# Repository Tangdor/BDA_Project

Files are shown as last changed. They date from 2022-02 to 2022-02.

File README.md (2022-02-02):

# Create your own BDA!

***
First, this is a university student project, BDA. It stands for Box Displayed Api's.

The purpose of our project is to develop an easy and fast device to facilitate daily tasks for students. 

Additionally, students should have the opportunity to continue to expand our device and its functions independently through their own ideas.

Among other things, this readme is here to make it easier for you to rebuild the device and the implementation that comes with it.
***

# Installation

## Hardware
What component parts are needed?:

- Raspberry PI Zero v.1.3, 1 Ghz, 512 MB Ram [1].

- The Waveshare 1.5 inch RGB OLED display [2].

- The rotary encoder is the AZ Delivery 5 * KY-040 [3].

In addition, sensors can still be attached. In our case we use 

- the gesture sensor Hailege 2pcs APDS-9960 APDS9960 RGB [4] 
- the temperature sensor AZDelivery DHT22 AM2302 [5]

<b> Raspberry Pi's Layout </b>

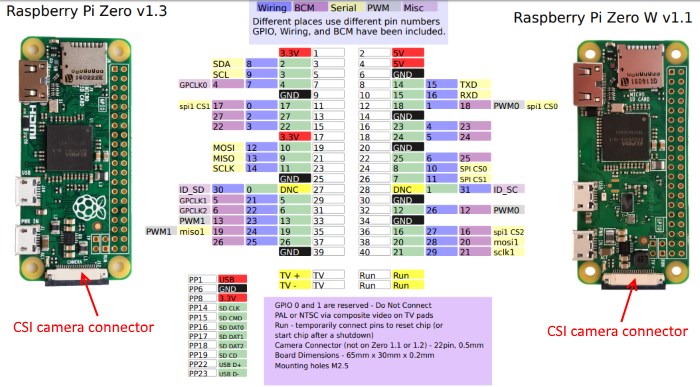
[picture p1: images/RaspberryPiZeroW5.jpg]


<b> Wiring diagram (simplified) </b>

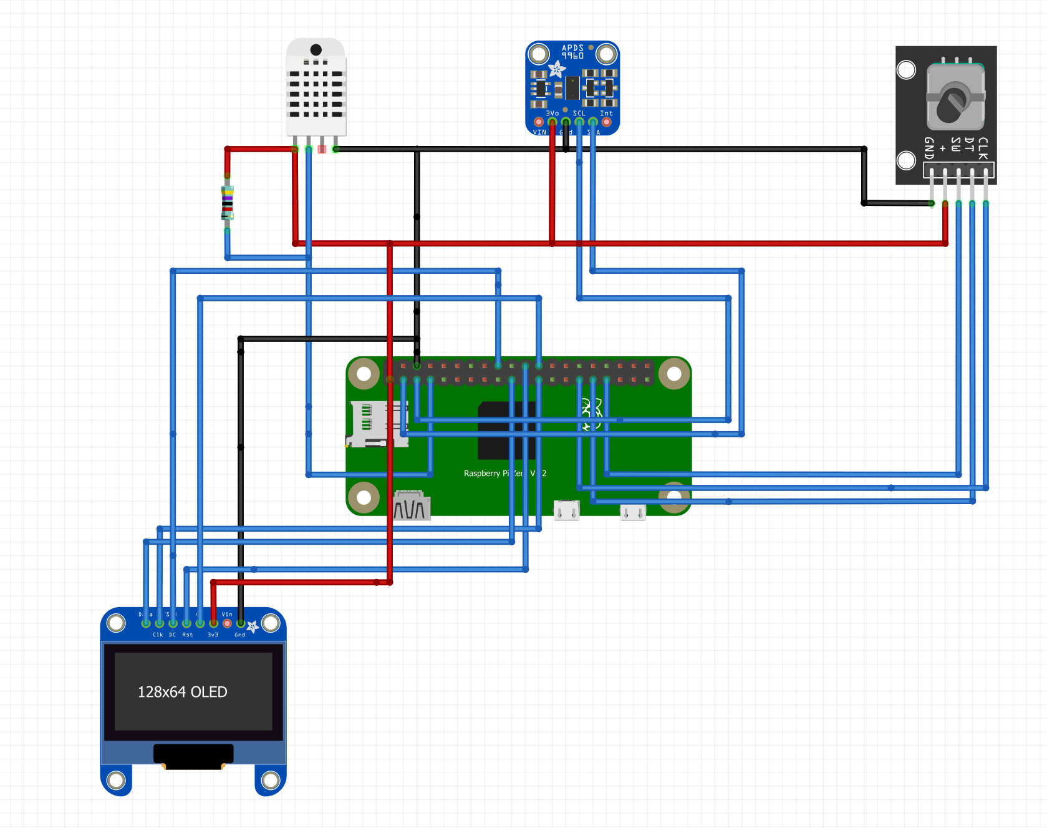
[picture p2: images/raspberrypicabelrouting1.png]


<b> Wiring diagram (detailed)  </b>

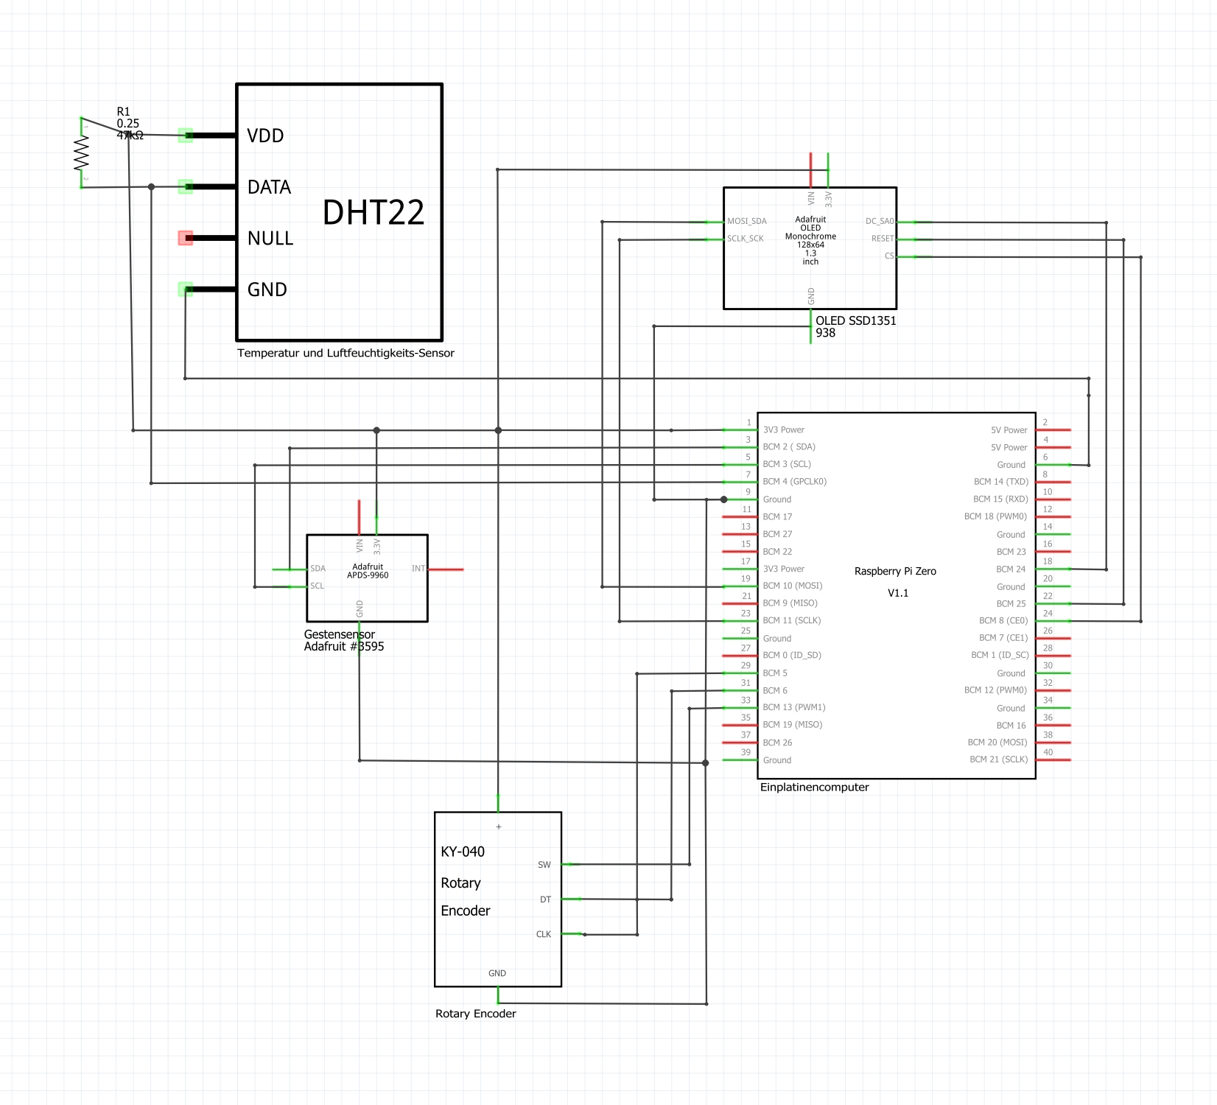
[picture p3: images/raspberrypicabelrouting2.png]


<b> The color affiliation for the cables are personalized, which means that it doesn't really matter how they are wired. 
It is only our choice of colors  </b>

<b>  Display </b>

| Raspberry Pi  | Color cable | Display  |
| --- | --- | --- |
| 3.3V 1 | red  | Vcc  |
| Ground 6 | black  | Ground  |
| MOSI bcm10  | blue  | MOSI  |
| SCLK bcm11  | yellow  | Clock  |
| SPICS0 bcm8  | orange  | CS (chip select) |
| bcm24  | green | DC (Data command)  |
| bcm25  | white  | reset  |

<b>  Rotary Encoder </b>

| Raspberry Pi  | Color cable | Rotary Encoder  |
| --- | --- | --- |
| GPIO 5 | purple  | CLK  |
| GPIO 6 | white  | DT  |
| GPIO 13  | yellow  | MOSI  |
| 3.3V  | red  | + |
| GND  | black  | GND|

<b> DHT22 </b>

| Raspberry Pi  | Color cable | DHT22  |
| --- | --- | --- |
| GND | black  | GND  |
| 3.3v | red  | VDD  |
| GPIO 4  | green  | DATA  |

<b> APDS9960 </b>

| Raspberry Pi  | Color cable | APDS9960  |
| --- | --- | --- |
| GND | black  | GND  |
| 3.3v | orange/red  | VCC  |
| SDA BCM2 PIN3  | green  | SDA  |
| SCL BCM3 PIN5  | white  | SCL  |

## Software
 - The Flask framework must be installed. [6]
### References
<b> For the individual installations I will direct you to the GitHub repositories. There you will find out more </b>

#### gesture sensore [8]

#### display  [9]

#### volume changer [10]

- pip install pycaw
- pip install comtypes

#### email  [11]

#### temperature sensor [12]

Website links: 

<b>  The website links I show you here might not be up to date at a later date. </b>

[1]: https://www.reichelt.de/de/de/raspberry-pi-zero-v-1-3-1-ghz-512-mb-ram-rasp-pi-zero-p256439.html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

[2]: https://www.amazon.de/gp/product/B07DB5YFGW/ref=ppx_yo_dt_b_asin_title_o01_s00?ie=UTF8&psc=1

[3]: https://www.amazon.de/AZDelivery-KY-040-Encoder-Compatible-Arduino/dp/B07CMVQHLT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

[4]: https://www.amazon.de/Gestensensormodul-Handgestenerkennung-Bewegungsrichtung-N%C3%A4herungssensor-Bewegungssensor/dp/B07YJDBFSD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

[5]: https://www.amazon.de/dp/B06XF4TNT9/ref=cm_sw_r_oth_api_glt_i_12DKYP86ENPG24TRVQXB?_encoding=UTF8&psc=1

[6]: https://code.visualstudio.com/docs/python/tutorial-flask

[7]: https://github.com/conradstorz/KY040

[8]: https://github.com/liske/python-apds9960

[9]: https://www.bluetin.io/displays/oled-display-raspberry-pi-ssd1331/

[10]: https://github.com/AndreMiras/pycaw

[11]: https://www.thepythoncode.com/article/reading-emails-in-python

[12]: https://github.com/adafruit/Adafruit_Python_DHT

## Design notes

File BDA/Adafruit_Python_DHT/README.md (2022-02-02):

*DEPRECATED LIBRARY* Adafruit Python DHT Sensor Library
=======================

his library has been deprecated! We are leaving this up for historical and research purposes but archiving the repository.

We are now only supporting the use of our CircuitPython libraries for use with Python.

Check out this guide for info on using DHT sensors with the CircuitPython library: https://learn.adafruit.com/dht-humidity-sensing-on-raspberry-pi-with-gdocs-logging/python-setup

---------------------------------------

Python library to read the DHT series of humidity and temperature sensors on a
Raspberry Pi or Beaglebone Black.

Designed specifically to work with the Adafruit DHT series sensors ---->
https://www.adafruit.com/products/385

Currently the library is tested with Python 2.6, 2.7, 3.3 and 3.4. It should
work with Python greater than 3.4, too.

Installing
----------

### Dependencies

For all platforms (Raspberry Pi and Beaglebone Black) make sure your system is
able to compile and download Python extensions with **pip**:

On Raspbian or Beaglebone Black's Debian/Ubuntu image you can ensure your
system is ready by running one or two of the following sets of commands:

Python 2:

````sh
sudo apt-get update
sudo apt-get install python-pip
sudo python -m pip install --upgrade pip setuptools wheel
````

Python 3:

````sh
sudo apt-get update
sudo apt-get install python3-pip
sudo python3 -m pip install --upgrade pip setuptools wheel
````

### Install with pip

Use `pip` to install from PyPI.

Python 2:

```sh
sudo pip install Adafruit_DHT
```

Python 3:

```sh
sudo pip3 install Adafruit_DHT
```

### Compile and install from the repository

First download the library source code from the [GitHub releases
page](https://github.com/adafruit/Adafruit_Python_DHT/releases), unzipping the
archive, and execute:

Python 2:

```sh
cd Adafruit_Python_DHT
sudo python setup.py install
```

Python 3:

```sh
cd Adafruit_Python_DHT
sudo python3 setup.py install
```

You may also git clone the repository if you want to test an unreleased
version:

```sh
git clone https://github.com/adafruit/Adafruit_Python_DHT.git
```

Usage
-----

See example of usage in the examples folder.

Author
------

Adafruit invests time and resources providing this open source code, please
support Adafruit and open-source hardware by purchasing products from Adafruit!

Written by Tony DiCola for Adafruit Industries.

MIT license, all text above must be included in any redistribution

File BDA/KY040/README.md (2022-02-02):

#KY040 Python Module 
##Martin O'Hanlon (martin@ohanlonweb.com)
##http://www.stuffaboutcode.com

##Description
A python module for reading the values from a KY040 rotary encoder module using a raspberry pi [http://www.stuffaboutcode.com/2015/05/raspberry-pi-and-ky040-rotary-encoder.html]([http://www.stuffaboutcode.com/2015/05/raspberry-pi-and-ky040-rotary-encoder.html])

##Version history
* 0.1 - Initial stable version
* 0.2 - Minor improvement

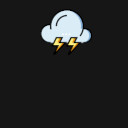
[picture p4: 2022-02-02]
BDA/weatherThunderstorm.jpg

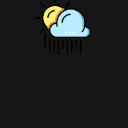
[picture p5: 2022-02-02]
BDA/weatherRain.jpg

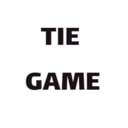
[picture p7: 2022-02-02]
BDA/tie.jpg

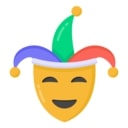
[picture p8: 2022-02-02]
BDA/jokeApp.jpg

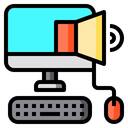
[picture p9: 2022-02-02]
BDA/computer.jpg

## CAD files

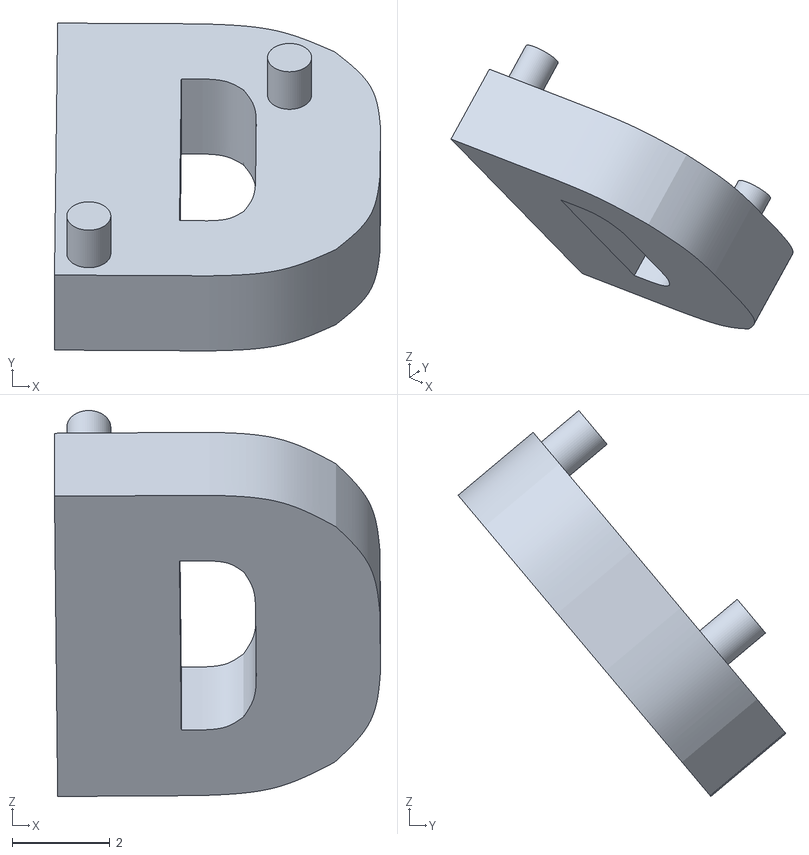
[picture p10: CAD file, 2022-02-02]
Model/Front label text D.stl
6.66 x 6.69 x 7.88

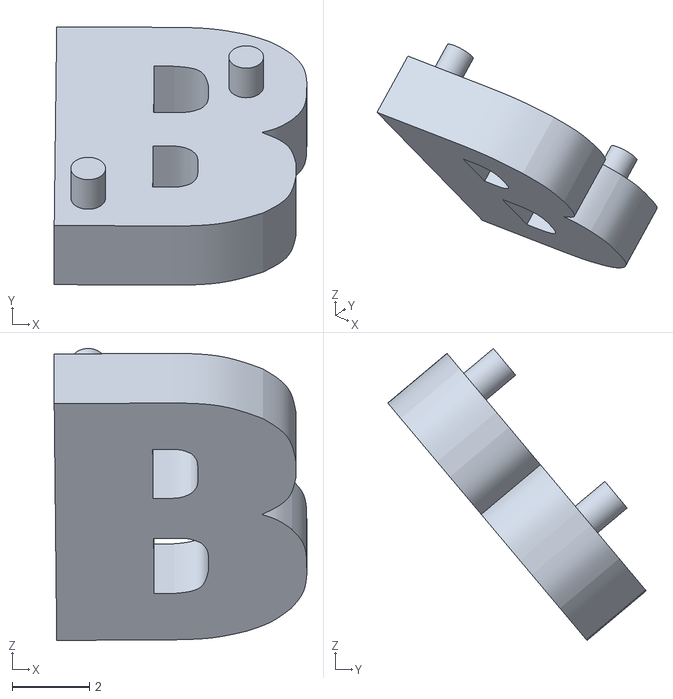
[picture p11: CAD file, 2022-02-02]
Model/Front label text B.stl
6.54 x 6.69 x 7.56

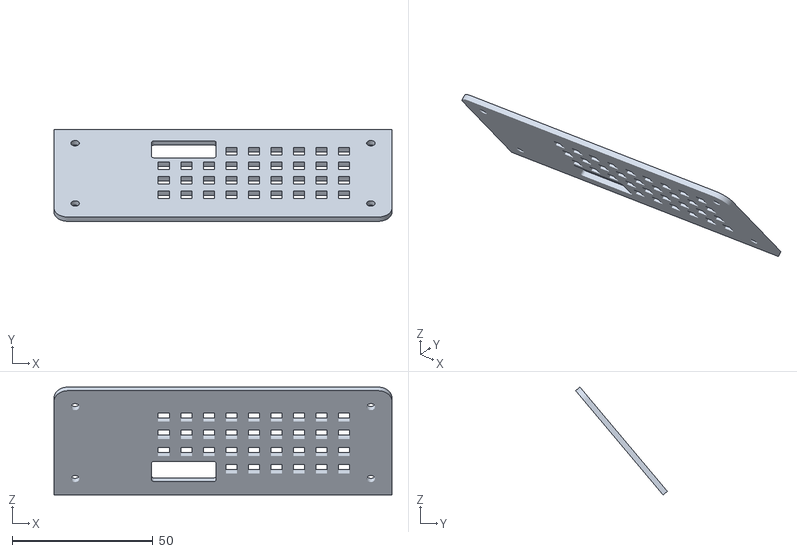
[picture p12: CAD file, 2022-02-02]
Model/Rear case doori.stl
120.0 x 32.6 x 38.3

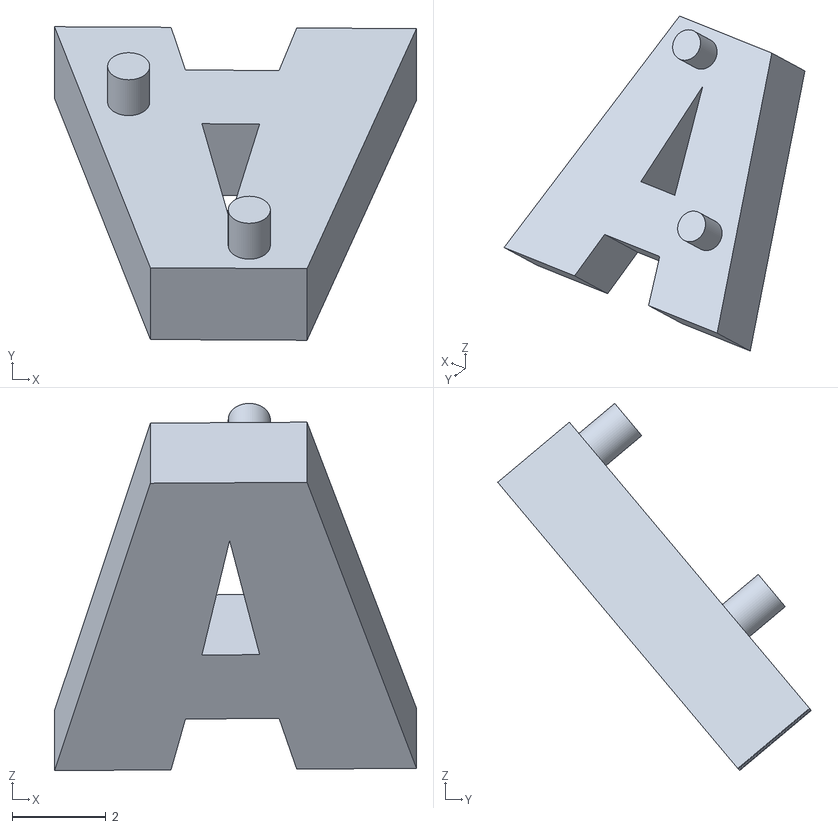
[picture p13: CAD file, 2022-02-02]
Model/Front label text A.stl
7.74 x 6.70 x 7.85

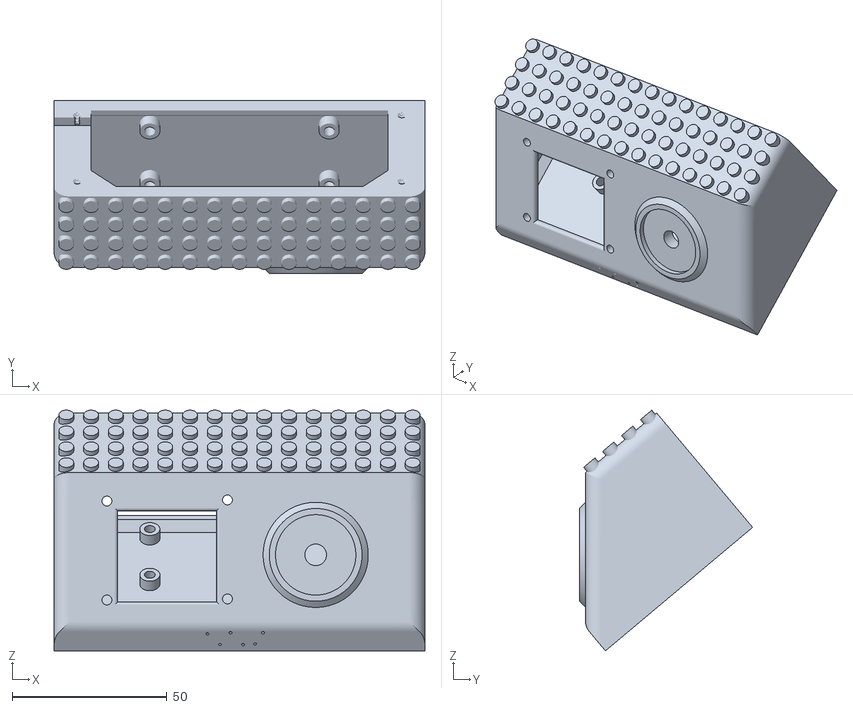
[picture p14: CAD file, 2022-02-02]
Model/BDA.stl
120.0 x 56.0 x 77.9

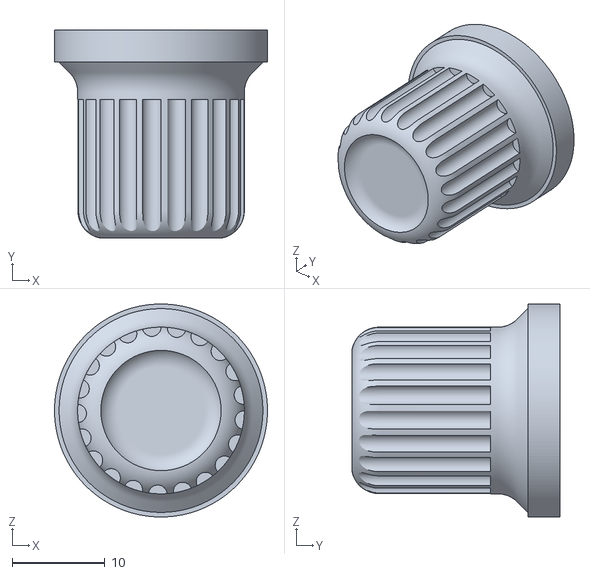
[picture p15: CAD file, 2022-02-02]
Model/Knob.stl
23.0 x 22.5 x 23.0

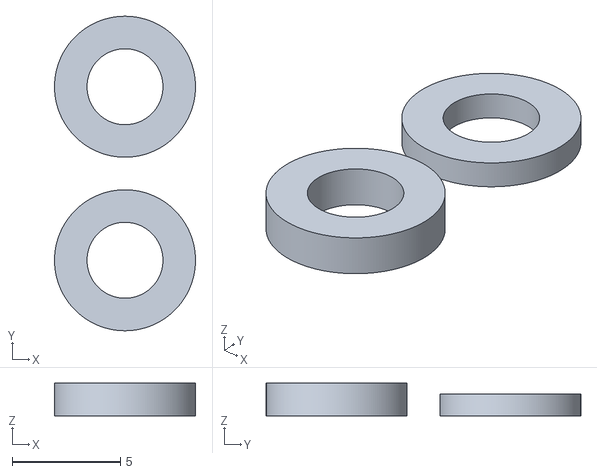
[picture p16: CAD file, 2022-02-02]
Model/Washer.stl
6.50 x 14.5 x 1.50

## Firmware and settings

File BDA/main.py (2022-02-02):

from apds9960.const import *
from apds9960 import APDS9960
import RPi.GPIO as GPIO
import smbus
from time import sleep
import math
import time
import datetime
from demo_opts import get_device
from luma.core.render import canvas
from KY040.KY040 import KY040
import os
from PIL import Image
from PIL import ImageDraw
from PIL import ImageFont
from luma.core.interface.serial import spi
from luma.oled.device import ssd1351
import sys
from TTTField import TTTField
import requests
import json
from flask import Flask,make_response
import configparser
from urllib.request import urlopen
import xmltodict 
from requests.structures import CaseInsensitiveDict
import imaplib
import email
from email.header import decode_header
import webbrowser
import Adafruit_DHT


app = Flask(__name__)

# Sensortype and GPIO for the temperaturesensor
sensor = Adafruit_DHT.DHT22
pin = '4'

# Initialization of the display
serial= spi(device=0, port=0)
device = ssd1351(serial_interface=serial, width=128, height=128, rotate=2, framebuffer=None, h_offset=0, v_offset=0, bgr=True)



# URL to the tomtom api
apiURL      = "https://api.tomtom.com/routing/1/calculateRoute/"
# apiKey
apiKey      = "insert your created TomTom API key"





# Variables for the volume app
muted = False
inVolumeApp = False
pressedCounter = 0
volumeCounter = 20



# this is used for the app menue, to keep track when a new app should be displayed and which
oldState = True 
counterPictures = 0 

# this is used for TicTacToe to keep track of what we should display
counterField = 0 
oldField = True 
xMarker = True 
movedField = True 
counterMarked = 0

# Variables used to keep track what we should display in each app
weatherCounter = 0
weatherOldState = True
trafficCounter = 0
trafficOldState = True
coronaCounter = 0
coronaOldState = True
mailCounter = 0
mailOldState = True
jokeCounter = 0
jokeOldState = True
calendarCounter = 0
calendarOldState = True
trainCounter = 0
trainOldState = True

# account credentials
username = "aliuetest99@gmail.com"
password = "#!test!#"

# Initialization of the motion sensor , every motion we use, we use inverted since our motion sensor is mounted on its head on our BDA, so left is right etc.
port = 1
bus = smbus.SMBus(port)
apds = APDS9960(bus)

# fields for our TicTacToe App
Field1 = TTTField(1,1,1,False,"")
Field2 = TTTField(41,1,2,False,"")
Field3 = TTTField(81,1,3,False,"")
Field4 = TTTField(1,41,4,False,"")
Field5 = TTTField(41,41,5,False,"")
Field6 = TTTField(81,41,6,False,"")
Field7 = TTTField(1,81,7,False,"")
Field8 = TTTField(41,81,8,False,"")
Field9 = TTTField(81,81,9,False,"")

# our Image Variable which we use everywhere with different pictures
frameSize = (128,128)
im = Image.new('RGB', (frameSize), 'black')


# pictures for the applicationss
def pictureOne():
    global im
    im = Image.open("/home/pi/BDA/zimmertemperatur.jpg")
    device.display(im)
def pictureTwo():
    global im
    im = Image.open("/home/pi/BDA/calendar.jpg")
    device.display(im)
def pictureThree():
    global im
    im = Image.open("/home/pi/BDA/mailed.jpg")
    device.display(im)
def pictureFour():
    global im
    im = Image.open("/home/pi/BDA/cars.jpg")
    device.display(im)
def pictureFive():
    global im
    im = Image.open("/home/pi/BDA/TTTicon.jpg")
    device.display(im)
def pictureSix():
    global im
    im = Image.open("/home/pi/BDA/computer.jpg")
    device.display(im)
def pictureSeven():
    global im
    im = Image.open("/home/pi/BDA/train.jpg")
    device.display(im)
def pictureEight():
    global im
    im = Image.open("/home/pi/BDA/weather.jpg")
    device.display(im)
def pictureNine():
    global im
    im = Image.open("/home/pi/BDA/corona.jpg")
    device.display(im)
def pictureTen():
    global im
    im = Image.open("/home/pi/BDA/jokeApp.jpg")
    device.display(im)

# pictures for the weatherapp
def weatherClearSky():
    global im
    im = Image.open("/home/pi/BDA/weatherClearSky.jpg")
def weatherBrokenClouds():
    global im
    im = Image.open("/home/pi/BDA/weatherBrokenClouds.jpg")
def weatherFewClouds():
    global im
    im = Image.open("/home/pi/BDA/weatherFewClouds.jpg")
def weatherMist():
    global im
    im = Image.open("/home/pi/BDA/weatherMist.jpg")
def weatherRain():
    global im
    im = Image.open("/home/pi/BDA/weatherRain.jpg")
def weatherScatteredClouds():
    global im
    im = Image.open("/home/pi/BDA/weatherScatteredClouds.jpg")
def weatherShowerRain():
    global im
    im = Image.open("/home/pi/BDA/weatherShowerRain.jpg")
def weatherSnow():
    global im
    im = Image.open("/home/pi/BDA/weatherSnow.jpg")
def weatherThunderstorm():
    global im
    im = Image.open("/home/pi/BDA/weatherThunderstorm.jpg")


def switchPressed(status): # everytime you press the button of the Rotary Encoder this will happen, in our case two times because it sends a signal when going down and going up, so we needed to account for that
     global counterPictures
     global im
     global muted 
     global pressedCounter
     global volumeCounter 
     pressedCounter += 1 # used to catch the second signal when the button is going up
     xCoordinate = 6 # is used to dynamic create the volume display. it counts in 6 pixel increments to move the rectangles we create
   
     if (inVolumeApp): # is only accessed when we are in the volume app, since it can always listen for interrupts we need to stop it from potentialy doing things when not in the right app
      if (muted and pressedCounter == 1):
       url = "#your-ip-adress/volume/unmute" # your target needs to host the EP which you can find under "Volume App Code for the PC" in this Repo 
       response = requests.get(url)                     # this url is the app adress of that host with the path to unmute the host, below are the paths to mute and for the volume control
       muted = False
       im = Image.new('RGB', (frameSize), 'black') # rest is used to create the volume display 
       draw = ImageDraw.Draw(im)    
       font = ImageFont.truetype("FreeMonoBold.ttf", 10)
       draw.text((15,5), "Volume Controller" , fill="white", font=font)
       font = ImageFont.truetype("FreeMonoBold.ttf", 15)
       draw.text((55,55), str(volumeCounter*5) , fill="white", font=font)
       draw.text((35,80), "Unmuted" , fill="white", font=font)
       draw.rectangle([(5,25),(125,45)],outline="white",fill= None,width=1)
       for x in range(volumeCounter):    
        draw.rectangle([(xCoordinate,26),(xCoordinate+5,44)],outline="white",fill= "red",width=1)
        xCoordinate += 6 
       device.display(im)            
      elif (not muted and pressedCounter == 1):
       url = "#your-ip-adress/volume/mute"
       response = requests.get(url)
       muted = True  
       im = Image.new('RGB', (frameSize), 'black')
       draw = ImageDraw.Draw(im)    
       font = ImageFont.truetype("FreeMonoBold.ttf", 10)
       draw.text((15,5), "Volume Controller" , fill="white", font=font)
       font = ImageFont.truetype("FreeMonoBold.ttf", 15)
       draw.text((55,55), str(volumeCounter*5) , fill="white", font=font)
       draw.text((35,80), "Muted" , fill="white", font=font)
       draw.rectangle([(5,25),(125,45)],outline="white",fill= None,width=1)
       for x in range(volumeCounter):    
        draw.rectangle([(xCoordinate,26),(xCoordinate+5,44)],outline="white",fill= "red",width=1) 
        xCoordinate += 6        
       device.display(im)       
     if ( pressedCounter == 2): # is used to catch the second signal when the button is going up
       pressedCounter = 0
     if counterPictures == 5: # if we are in the TicTacToe app this button marks instead the fields with X and O
      if status == 13:
        markingTTT()

def rotaryChange(direction): # everytime you rotate the Rotary Encoder this will be accessed
  global im
  global volumeCounter
  global muted
  xCoordinate = 6 # same as in switchedPressed
  if (inVolumeApp): # is only accessed when we are in the volume app, since it can always listen for interrupts we need to stop it from potentialy doing things when not in the right app
    im = Image.new('RGB', (frameSize), 'black')
    draw = ImageDraw.Draw(im)    
    font = ImageFont.truetype("FreeMonoBold.ttf", 10)
    draw.text((15,5), "Volume Controller" , fill="white", font=font)
    font = ImageFont.truetype("FreeMonoBold.ttf", 15)
    if muted:
     draw.text((35,80), "Muted" , fill="white", font=font)
    else :
     draw.text((35,80), "Unmuted" , fill="white", font=font)   
    draw.rectangle([(5,25),(125,45)],outline="white",fill= None,width=1)    
    if ( direction == 0):
      url = "#your-ip-adress/volume/down" # same as above, only this is the url to regulate the volume down in 5% steps
      response = requests.get(url) 
      if (volumeCounter > 0):
       volumeCounter -= 1
      draw.text((55,55), str(volumeCounter*5) , fill="white", font=font)
      if (volumeCounter != 0):
       for x in range(volumeCounter):    
        draw.rectangle([(xCoordinate,26),(xCoordinate+5,44)],outline="white",fill= "red",width=1)     
        xCoordinate += 6 
      device.display(im)        
      sleep(0.2)
    if ( direction == 1):
      url = "#your-ip-adress/volume/up" # same as above, only this is the url to regulate the volume up in 5% steps
      response = requests.get(url)      
      if (volumeCounter < 20):
       volumeCounter += 1
      else : 
        volumeCounter = 20 
      draw.text((55,55), str(volumeCounter*5) , fill="white", font=font)        
      for x in range(volumeCounter):    
        draw.rectangle([(xCoordinate,26),(xCoordinate+5,44)],outline="white",fill= "red",width=1)     
        xCoordinate += 6 
      device.display(im)  
      sleep(0.2)     
 

def makeFieldTTT():
    global Field1,Field2,Field3,Field4,Field5,Field6,Field7,Field8,Field9
    global im
    im = Field1.whiteField(im)
    im = Field2.whiteField(im)
    im = Field3.whiteField(im)
    im = Field4.whiteField(im)
    im = Field5.whiteField(im)
    im = Field6.whiteField(im)
    im = Field7.whiteField(im)
    im = Field8.whiteField(im)
    im = Field9.whiteField(im)
    device.display(im)

def resetTTT():
    global counterMarked
    global Field1,Field2,Field3,Field4,Field5,Field6,Field7,Field8,Field9
    Field1 = TTTField(1,1,1,False,"")
    Field2 = TTTField(41,1,2,False,"")
    Field3 = TTTField(81,1,3,False,"")
    Field4 = TTTField(1,41,4,False,"")
    Field5 = TTTField(41,41,5,False,"")
    Field6 = TTTField(81,41,6,False,"")
    Field7 = TTTField(1,81,7,False,"")
    Field8 = TTTField(41,81,8,False,"")
    Field9 = TTTField(81,81,9,False,"")
    counterMarked = 0

def markingTTT(): 
       global im
       global xMarker
       global movedField
       global counterField
       global counterMarked
       # we hardcoded this step to be able to see each marked field
       if counterField == 0:
        if xMarker == True and movedField == True and Field1.marked == False:
         im = Field1.setMarker("X",im)
         counterMarked += 1
         xMarker = False
         movedField = False
        elif xMarker == False and movedField == True and Field1.marked == False:
         im = Field1.setMarker("O",im)
         counterMarked += 1
         xMarker = True
         movedField = False
       elif counterField == 1:
        if xMarker == True and movedField == True and Field2.marked == False:
         im = Field2.setMarker("X",im)
         counterMarked += 1
         xMarker = False
         movedField = False
        elif xMarker == False and movedField == True and Field2.marked == False:
         im = Field2.setMarker("O",im)
         counterMarked += 1
         xMarker = True
         movedField = False
       elif counterField == 2:
        if xMarker == True and movedField == True and Field3.marked == False:
         im = Field3.setMarker("X",im)
         counterMarked += 1
         xMarker = False
         movedField = False
        elif xMarker == False and movedField == True and Field3.marked == False:
         im = Field3.setMarker("O",im)
         counterMarked += 1
         xMarker = True
         movedField = False
       elif counterField == 3:
        if xMarker == True and movedField == True and Field4.marked == False:
         im = Field4.setMarker("X",im)
         counterMarked += 1
         xMarker = False
         movedField = False
        elif xMarker == False and movedField == True and Field4.marked == False:
         im = Field4.setMarker("O",im)
         counterMarked += 1
         xMarker = True
         movedField = False
       elif counterField == 4:
        if xMarker == True and movedField == True and Field5.marked == False:
         im = Field5.setMarker("X",im)
         counterMarked += 1
         xMarker = False
         movedField = False
        elif xMarker == False and movedField == True and Field5.marked == False:
         im = Field5.setMarker("O",im)
         counterMarked += 1
         xMarker = True
         movedField = False
       elif counterField == 5:
        if xMarker == True and movedField == True and Field6.marked == False:
         im = Field6.setMarker("X",im)
         counterMarked += 1
         xMarker = False
         movedField = False
        elif xMarker == False and movedField == True and Field6.marked == False:
         im = Field6.setMarker("O",im)
         counterMarked += 1
         xMarker = True
         movedField = False
       elif counterField == 6:
        if xMarker == True and movedField == True and Field7.marked == False:
         im = Field7.setMarker("X",im)
         counterMarked += 1
         xMarker = False
         movedField = False
        elif xMarker == False and movedField == True and Field7.marked == False:
         im = Field7.setMarker("O",im)
         counterMarked += 1
         xMarker = True
         movedField = False
       elif counterField == 7:
        if xMarker == True and movedField == True and Field8.marked == False:
         im = Field8.setMarker("X",im)
         counterMarked += 1
         xMarker = False
         movedField = False
        elif xMarker == False and movedField == True and Field8.marked == False:
         im = Field8.setMarker("O",im)
         counterMarked += 1
         xMarker = True
         movedField = False
       elif counterField == 8:
        if xMarker == True and movedField == True and Field9.marked == False:
         im = Field9.setMarker("X",im)
         counterMarked += 1
         xMarker = False
         movedField = False
        elif xMarker == False and movedField == True and Field9.marked == False:
         im = Field9.setMarker("O",im)
         counterMarked += 1
         xMarker = True
         movedField = False
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

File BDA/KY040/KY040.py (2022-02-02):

"""
KY040 Python Class
Martin O'Hanlon
stuffaboutcode.com


Additional code added by Conrad Storz 2015 and 2016
"""

import RPi.GPIO as GPIO
from time import sleep


class KY040:

    CLOCKWISE = 0
    ANTICLOCKWISE = 1
    DEBOUNCE = 12

    def __init__(self, clockPin, dataPin, switchPin, rotaryCallback, switchCallback):
        #persist values
        self.clockPin = clockPin
        self.dataPin = dataPin
        self.switchPin = switchPin
        self.rotaryCallback = rotaryCallback
        self.switchCallback = switchCallback

        #setup pins
        GPIO.setup(clockPin, GPIO.IN, pull_up_down=GPIO.PUD_UP)
        GPIO.setup(dataPin, GPIO.IN, pull_up_down=GPIO.PUD_UP)
        GPIO.setup(switchPin, GPIO.IN, pull_up_down=GPIO.PUD_UP)

    def start(self):
        GPIO.add_event_detect(self.clockPin, GPIO.FALLING, callback=self._clockCallback, bouncetime=self.DEBOUNCE)
        GPIO.add_event_detect(self.switchPin, GPIO.FALLING, callback=self.switchCallback, bouncetime=self.DEBOUNCE)

    def stop(self):
        GPIO.remove_event_detect(self.clockPin)
        GPIO.remove_event_detect(self.switchPin)

    def _clockCallback(self, pin):
        if GPIO.input(self.clockPin) == 0:
            self.rotaryCallback(GPIO.input(self.dataPin))
        """
            data = GPIO.input(self.dataPin)
            if data == 1:
                self.rotaryCallback(self.ANTICLOCKWISE)
            else:
                self.rotaryCallback(self.CLOCKWISE)

        self.rotaryCallback(GPIO.input(self.dataPin))
        """

    def _switchCallback(self, pin):
        """
        if GPIO.input(self.switchPin) == 0:
            self.switchCallback()
        """
        self.switchCallback()

#test
if __name__ == "__main__":

    print('Program start.')

    CLOCKPIN = 27
    DATAPIN = 22
    SWITCHPIN = 17

    def rotaryChange(direction):
        print("turned - " + str(direction))

    def switchPressed(pin):
        print("button connected to pin:{} pressed".format(pin))

    GPIO.setmode(GPIO.BCM)
    ky040 = KY040(CLOCKPIN, DATAPIN, SWITCHPIN, rotaryChange, switchPressed)

    print('Launch switch monitor class.')

    ky040.start()
    print('Start program loop...')
    try:
        while True:
            sleep(10)
            print('Ten seconds...')
    finally:
        print('Stopping GPIO monitoring...')
        ky040.stop()
        GPIO.cleanup()
        print('Program ended.')
